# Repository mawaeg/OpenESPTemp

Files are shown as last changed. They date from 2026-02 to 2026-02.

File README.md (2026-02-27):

# OpenESPTemp

**OpenESPTemp** is an open-source, battery-powered temperature and environmental monitoring sensor built using an ESP32-C6 and a BME280 sensor. It is designed for integration into IoT systems.

The PCB is designed to operate with a rechargeable LiFePo4 AA battery. This repository includes the PCB design, a 3D-printable case, and basic firmware.

<div style="display: flex;">
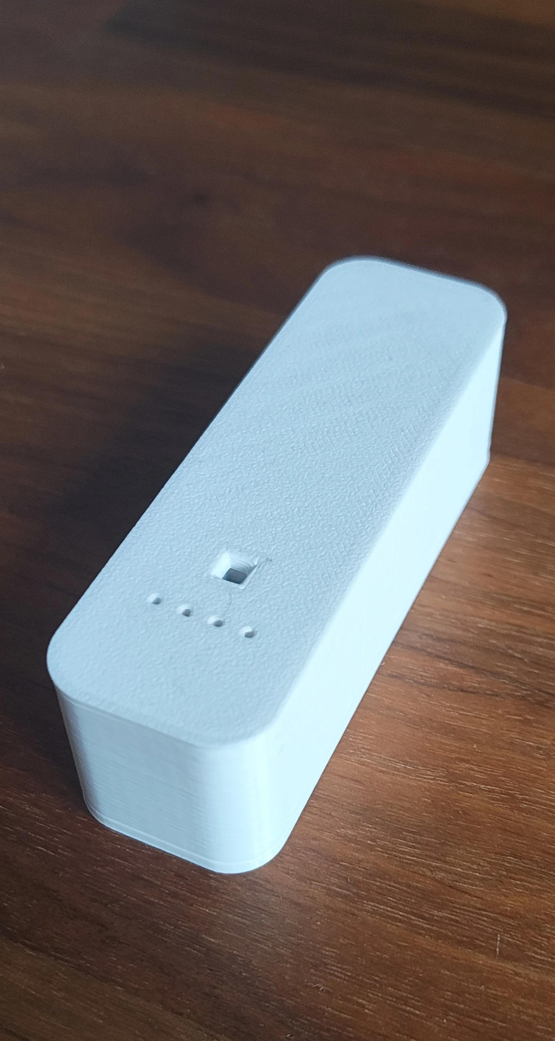
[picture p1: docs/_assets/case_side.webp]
Case Side
   
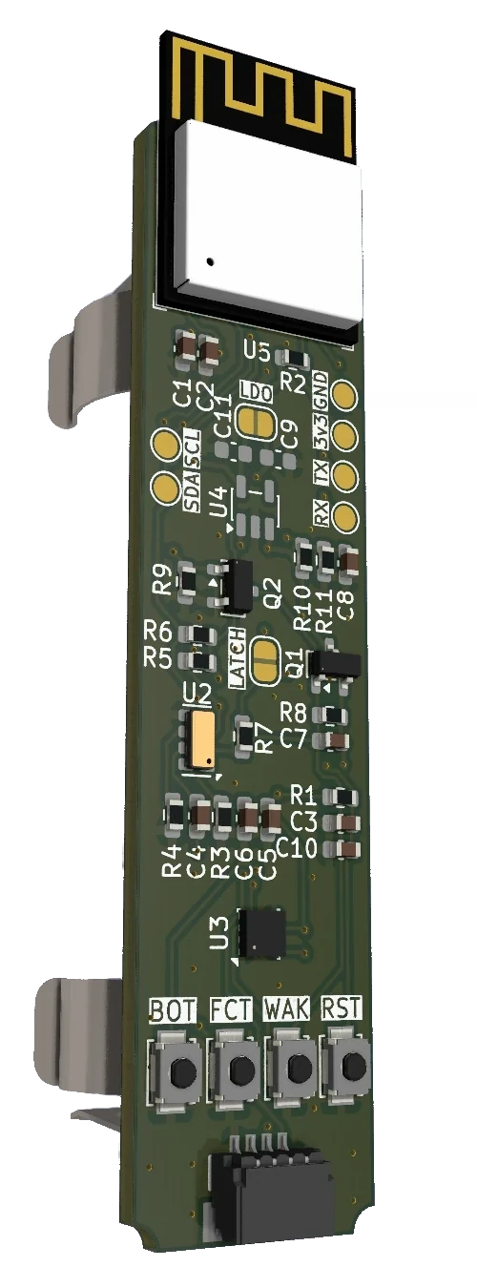
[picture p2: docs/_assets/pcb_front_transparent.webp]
PCB Front
   
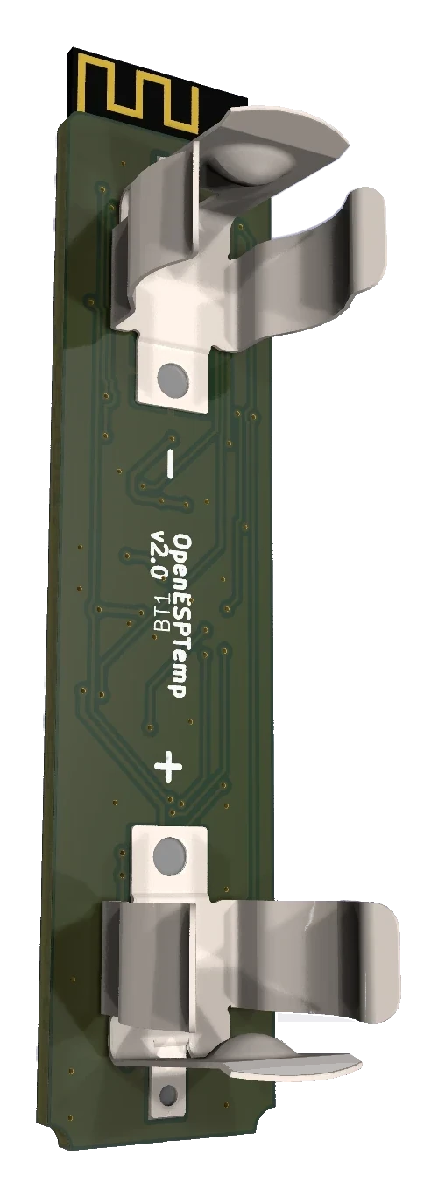
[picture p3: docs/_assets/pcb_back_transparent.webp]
PCB Back
   
</div>

---

## ✨ Features

- **Temperature Monitoring**: Provides readings using the BME280 sensor.
- **Environmental Sensing**: Includes humidity and pressure measurements.
- **Low Power**: Optimized for battery-powered operation (under 200nA power consumption while sleeping).
- **Battery Monitoring**: Allows monitoring of the battery voltage.
- **ESP32-C6 Microcontroller**: Handles wireless communication and processing.
- **Customizable PCB**: Features a Qwiic connector and the option to use an LDO when not using a LiFePo4 battery.
- **Open Source**: Fully customizable for specific use cases.
- **OTA updates**: Possibility to update the firmware over the air using ElegantOTA

---

## 🚀 Getting Started

### 1. The PCB

The PCB can be ordered from any PCB manufacturer (e.g., JLCPCB). It can be ordered as single boards or in panels of 5.

- **Manufacturing Files & BOM**: Included in the latest release. The Interactive HTML BOM (iBOM) is recommended for manual assembly.
- **SMT Assembly**: If using an SMT service, you will need to generate the BOM and position files yourself.

> **💡 Note:** You will need two Keystone 53 battery contacts; the BOM only mentions one.

### 2. Additional Parts

| Part | Quantity | Recommendation / Link | Note |
| :--- | :---: | :--- | :--- |
| **LiFePo4 AA (14500) battery (!Normal AA batteries won't work!)** | 1 | [LiFePo4 battery](https://de.aliexpress.com/item/1005005870958670.html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) | Any 3.2V LiFePo4 battery should work |
| **3D Printing Filament (PETG)** | ~50g | [White PETG Filament](https://www.nobufil.com/product-page/filament-petg-white) | |
| **UART to USB Adapter** | 1 | [CP2102 Adapter](https://de.aliexpress.com/item/1005006742102516.html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) | |
| **Pogo Pin Adapter** *(Optional)* | 1 | [4-Pin Prototyping Clamps](https://de.aliexpress.com/item/1005007887384238.html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) | Avoids soldering to test points. |

---

## 🛠️ Hardware Assembly

1. **Prepare the PCB**: Solder the components onto the PCB (if not using an SMT service).
   > **ℹ️ Info:** The LDO Solder Jumper is pre-closed for LiFePO4 battery use. If you choose to install an LDO, ensure you cut/open the jumper first.

   > **💡 Note:** If using a Pogo Adapter to flash the firmware, it should be flashed before mounting the battery holders, as the battery holder blocks access to the pins with the adapter.
2. **Print the Case**: Print using standard settings with a 0.2 mm layer height -  no supports needed.
   - The case does not require any screws, it holds together with snap connections
3. **Flash the Firmware**: Follow the instructions below to flash, and configure Wi-Fi/REST endpoint.
4. **Insert the Battery**:
   > **🛑 Warning:** Check the polarity carefully. Never connect the USB to UART adapter and the battery at the same time.
5. **Wake**: Press the WAK button for about a second. The sensor will start sending data periodically.

<div style="display: flex; gap: 20px;">
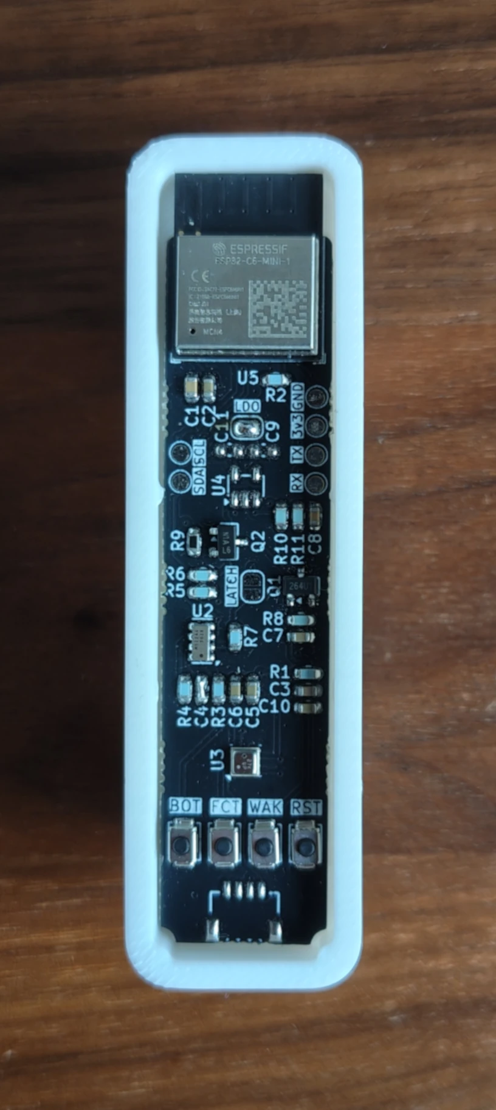
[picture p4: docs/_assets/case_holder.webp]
Case Pcb Holder
   
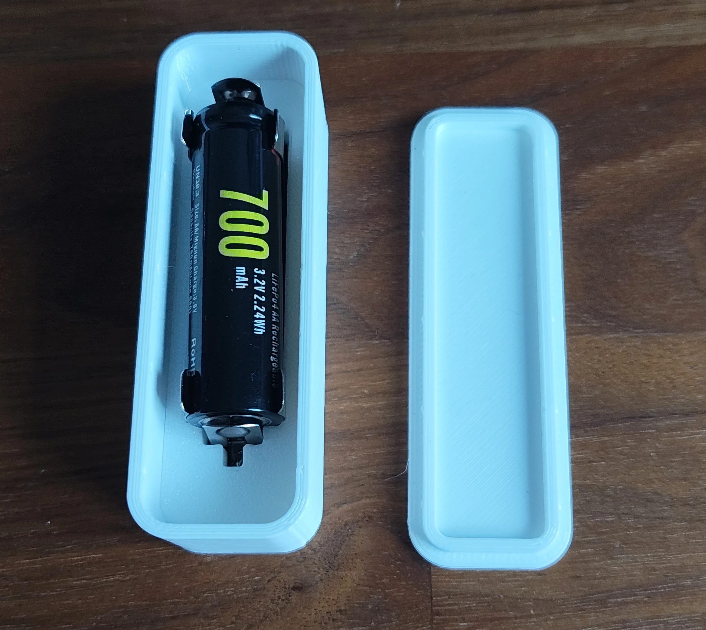
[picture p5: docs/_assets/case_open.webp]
Case open
   
</div>

---

## 💻 Firmware

By default, the sensor connects to a specified Wi-Fi network and sends data to a REST API endpoint every 15 minutes.

The firmware also allows to update itself using Over The Air updates using [ElegantOTA](https://github.com/ayushsharma82/ElegantOTA).
Read more about that [here](#flash-using-ota-update).

> **💡 Note:** Newer [releases](https://github.com/mawaeg/OpenESPTemp/releases) include a pre-compiled `.bin` file. If you use this, you can skip the compilation step.

### Compiling (PlatformIO)

The firmware can be compiled and flashed with [PlatformIO](https://platformio.org/). You can build in debug mode (to get Serial debug information) or release mode:

```bash
# Debug mode
platformio run --environment esp32-c6-debug

# Release mode
platformio run --environment esp32-c6
```

The firmware has to be flashed via the Serial Interface once. Afterwards it can be updated with [OTA updates](#flash-using-ota-update).

### Flashing

**Wiring:** Connect the UART to USB adapter to the PCB:

| UART Adapter | Direction | PCB | Note |
| :--- | :---: | :--- | :--- |
| **3V3** | ⟷ | **3V3** | Use 3.3V only (do not use 5V) |
| **GND** | ⟷ | **GND** | Common ground is required |
| **TX** | ⟶ | **RX** | Connect Transmit to Receive |
| **RX** | ⟵ | **TX** | Connect Receive to Transmit |

> **ℹ️ Info:** Remember to **cross** the data lines! The **TX** (Transmit) pin on the adapter must connect to the **RX** (Receive) pin on the PCB, and vice versa.

> **🛑 Warning:** You must disconnect the battery before connecting the UART to USB adapter!

#### Option A: Flashing via PlatformIO
Run the following command:
```bash
platformio run --target upload --environment esp32-c6
```
When `Looking for upload port...` appears in the console, put the ESP32 into boot mode:
1. Push the Reset and Boot buttons at the same time.
2. Release the Reset button while keeping the Boot button pressed.
3. The upload will start; release the Boot button.

#### Option B: Flashing via esptool (Precompiled Binary)
Flash the binary using [esptool](https://github.com/espressif/esptool):
```bash
python -m esptool --chip esp32-c6 --port <your-port> --baud 460800 write_flash -z 0x1000 firmware.bin
```
*(Put the ESP32 into boot mode as described above, and replace `<your-port>` with the correct serial port.)*

### Flash using OTA update

The firmware allows to update itself via OTA updates. For that to work the firmware has to be flashed via UART initially.

This is how to trigger a OTA update.
1. Follow steps 1 and 2 of [Reconfigure the device](#reconfigure-the-device)
4. Open **`http://192.168.4.1/update`** in a browser.
5. Here you can upload a new binary (Either get it from the [releases page](https://github.com/mawaeg/OpenESPTemp/releases) or compile it yourself as described [here](#compiling-(platformio))).
6. When uploading while powered by battery you should press and hold the WAK button during the update

---

## ⚙️ Configuration

After flashing, press the Reset button once to start the firmware. If unconfigured, the device will create a Wi-Fi network for setup:

1. Connect to the **`OpenESPTemp Configurator`** Wi-Fi network.
2. Open **`http://192.168.4.1`** in a browser.
3. Configure the following fields in the form:
   - **SSID**: Target Wi-Fi network name.
   - **Password**: Target Wi-Fi network password.
   - **Post URL**: The URL for the POST request.
   - **Authorization**: The Bearer token for authentication (do not include "Bearer", only the token).
4. Click submit. The configuration will be saved, and the device will restart.
5. The sensor will now operate as expected.

### Reconfigure the device

To reconfigure the OpenESPTemp after it has already been configured once, you need do the following:
1. Bring the OpenESPTemp in config mode:
   1. When connected to UART: Press and hold FCT button and press RST shortly. Release FCT after ~6 seconds
   2. When running with battery: Press and hold FCT button and press WAK for around a second. Release FCT after ~6 seconds
2. The OpenESPTemp will create a network called  **`OpenESPTemp Configurator`**. Connect to it.
3. Open **`http://192.168.4.1`** in a browser an reconfigure the fields. Refer to [⚙️ Configuration](#⚙️-configuration)

---

## ⚡ Power consumption

The OpenESPTemp aims to have a very low power consumption.

During sleep, the power consumption is below 200nA (200nA is the limit of the PPK 2, it is probably at around 50nA according to the RV3028-C7 datasheet):

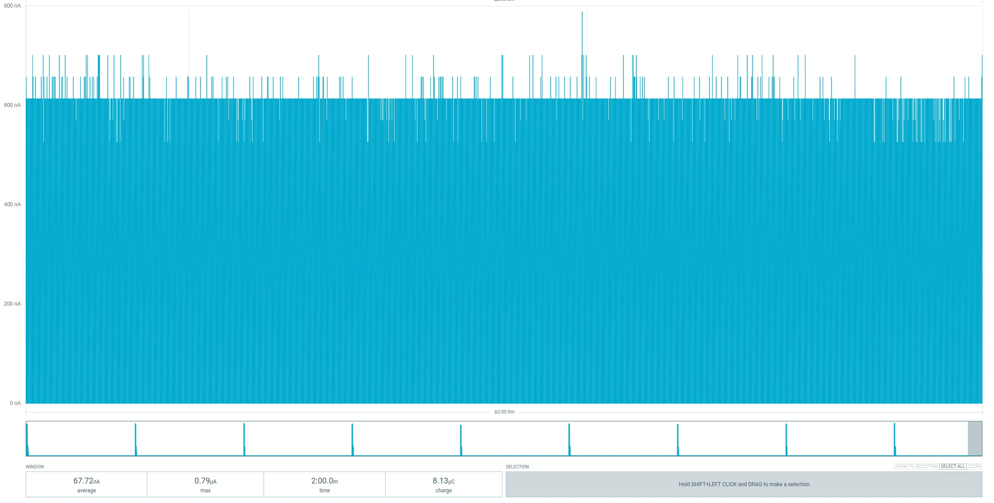
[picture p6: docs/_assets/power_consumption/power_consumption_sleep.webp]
Power consumption sleep


The power consumption for a whole cycle (15 min with sending data once) looks like this:

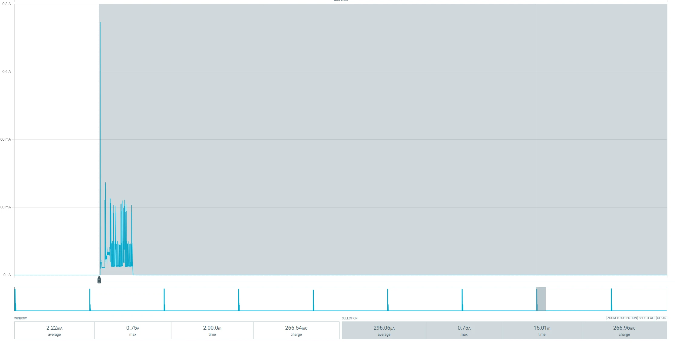
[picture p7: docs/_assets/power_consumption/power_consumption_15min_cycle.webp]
Power consumption 15 min cycle


The power consumption for active mode (sending data) looks the following:

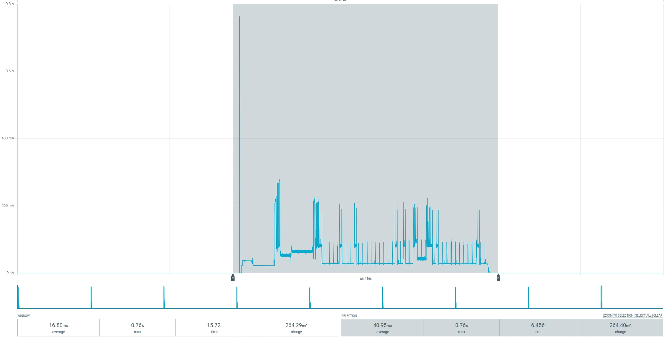
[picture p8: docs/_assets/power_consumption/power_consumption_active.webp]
Power consumption active


---

## 📐 PCB Design

The PCB was created using KiCad 9.0, the project files are located under [/electronics](/electronics).

The power latch used in this design was inspired by [this](https://circuitcellar.com/resources/quickbits/soft-latching-power-circuits/) article.

To generate a panel yourself using the provided script:
1. Install [KiKit](https://github.com/yaqwsx/KiKit).
2. Execute `/electronics/panelize.sh`.

The panel with the existing config looks like this:

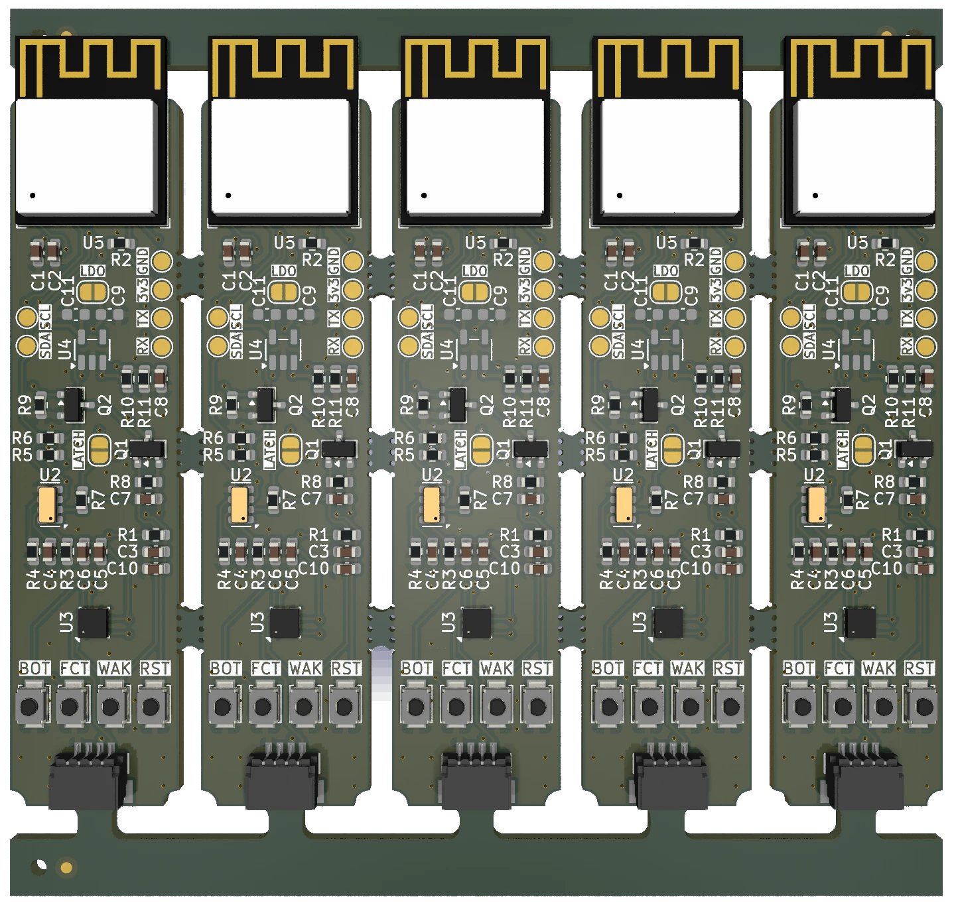
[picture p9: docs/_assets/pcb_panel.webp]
Flash wiring


---

## 🧊 CAD

The case was created using Onshape. To edit the case yourself click [here](https://cad.onshape.com/documents/398f777c8db5f4a69ffcddaa/w/b07485d077929fc2f0119cac/e/3395ca67b8682bc329248728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) and copy the project.

The current STL files are included in the repo under [/cad](/cad).

---

## 🚧 Troubleshooting

TBD

---

## 🗺️ Coming Next

- [ ] Include mounting bracket for the case
- [ ] Include HomeAssistant integration

---

## 📄 License

This project is licensed under the GNU General Public License v3.0. See the [LICENSE](LICENSE) file for details.

### Hardware Libraries
Various libraries were used to create the PCB. Copies of most libraries are included in `/electronics/libs/` to ensure the KiCad project works without manual installation.

Some of these libraries are licensed under their respective licenses. Please review the `README.md` file in the library folders.

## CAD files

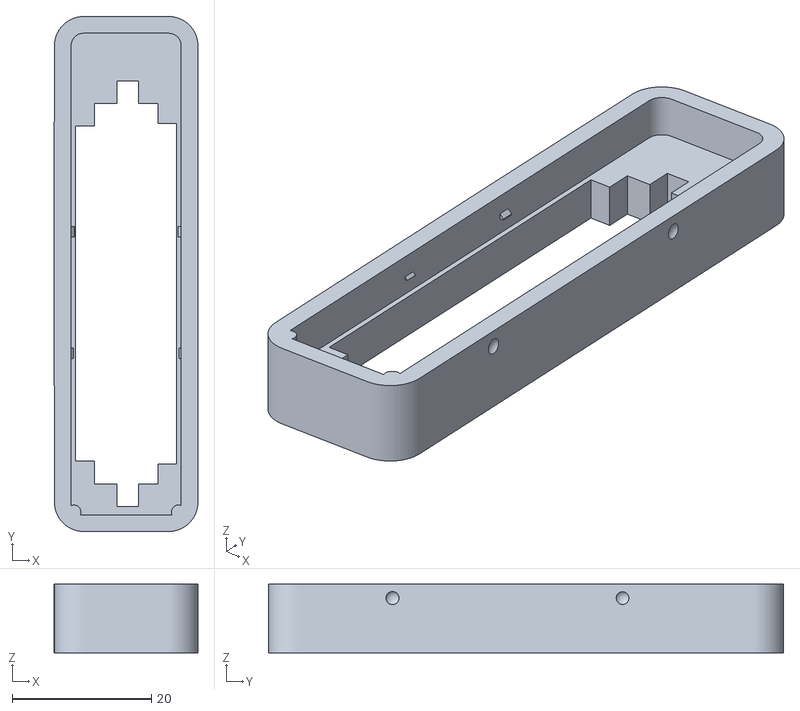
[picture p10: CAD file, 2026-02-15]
cad/pcb-holder.stl
20.7 x 73.9 x 9.86

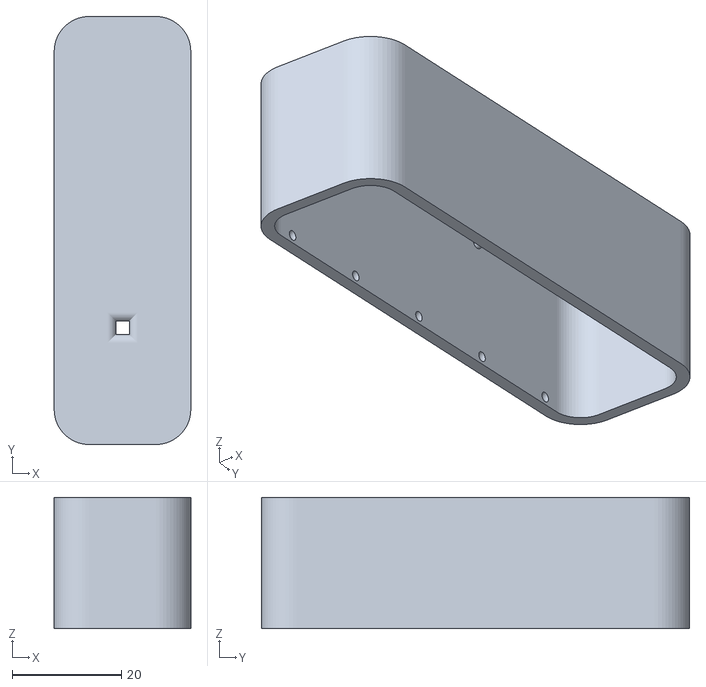
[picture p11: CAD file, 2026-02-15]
cad/case.stl
25.0 x 78.3 x 24.0

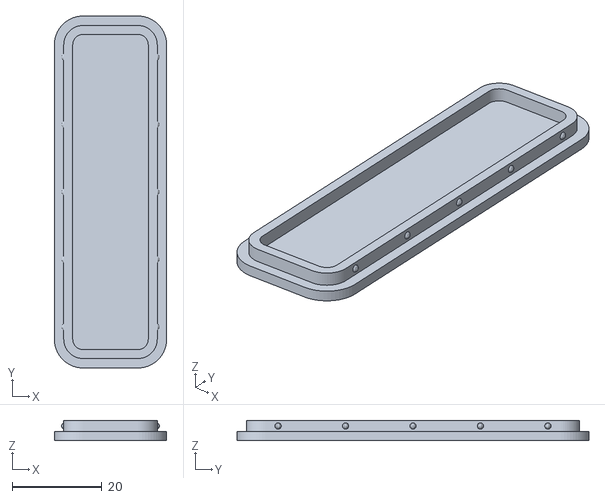
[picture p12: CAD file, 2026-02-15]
cad/top.stl
25.0 x 78.3 x 4.50

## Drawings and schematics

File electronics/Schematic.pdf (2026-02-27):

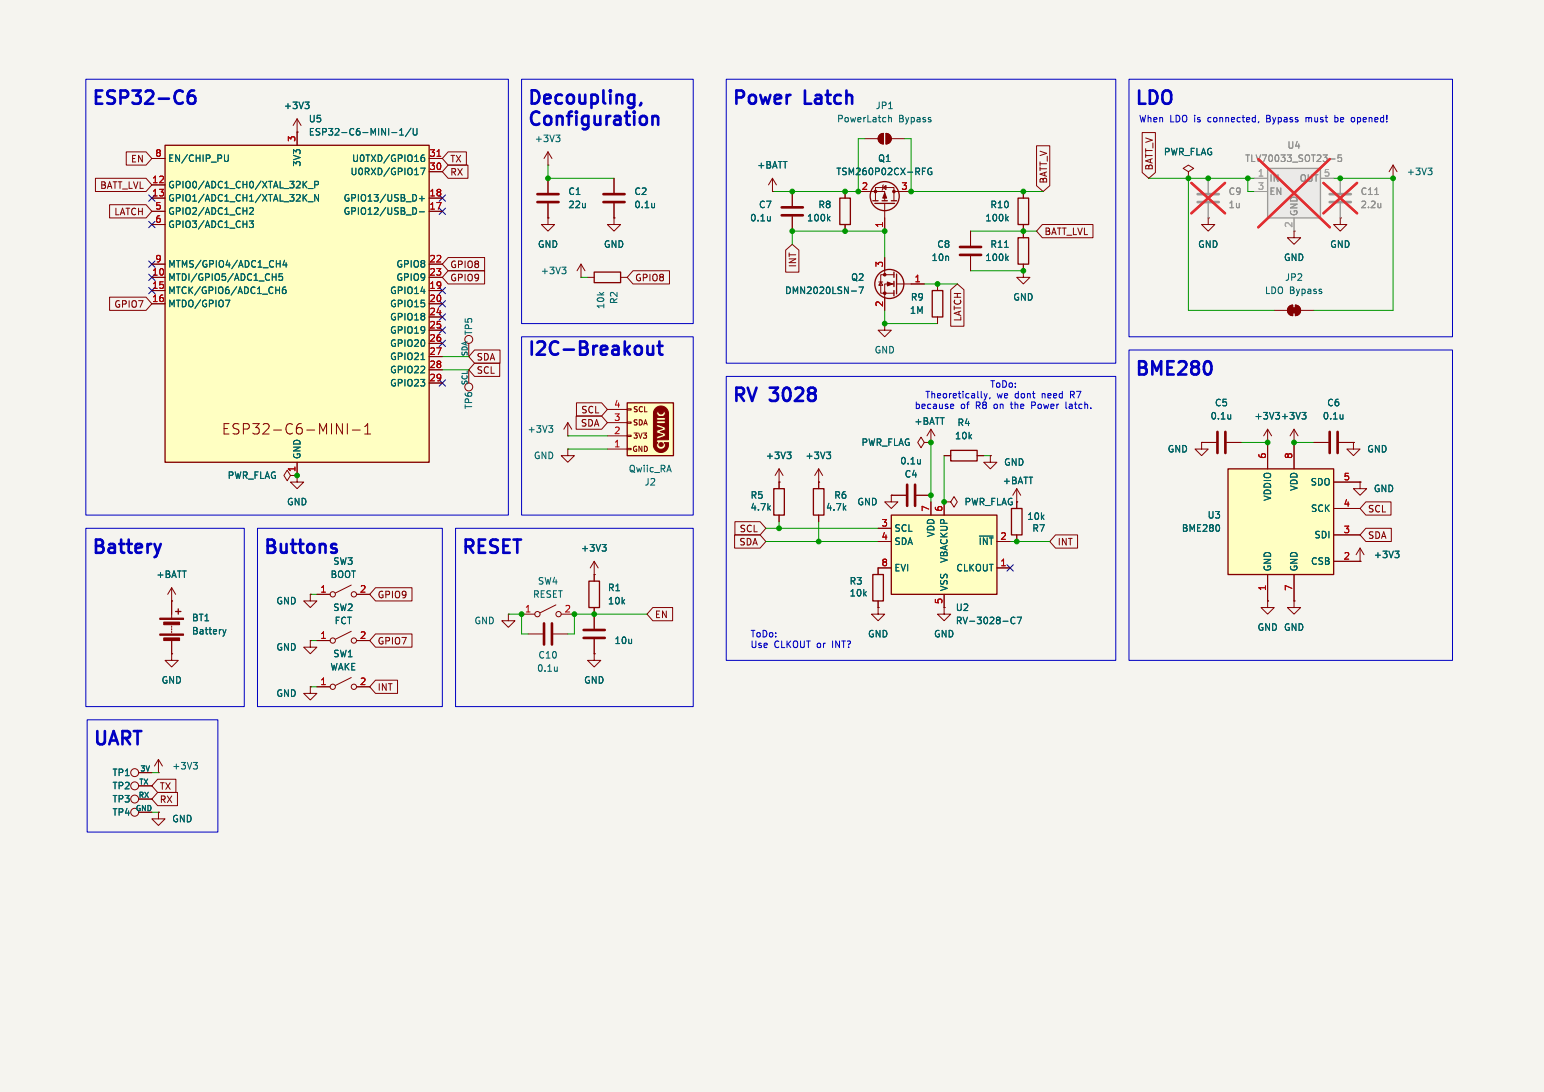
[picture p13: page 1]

7 SDO 5 SCK 4 SDI 3 CSB 2 GND Q1 TSM260P02CX-RFG

3 2 Q2 DMN2020LSN-7 TP4 GND TP3 RX GND GND GND

7 SDO 5 SCK 4 SDI 3 CSB 2 U3 BME280 TP6 SCL

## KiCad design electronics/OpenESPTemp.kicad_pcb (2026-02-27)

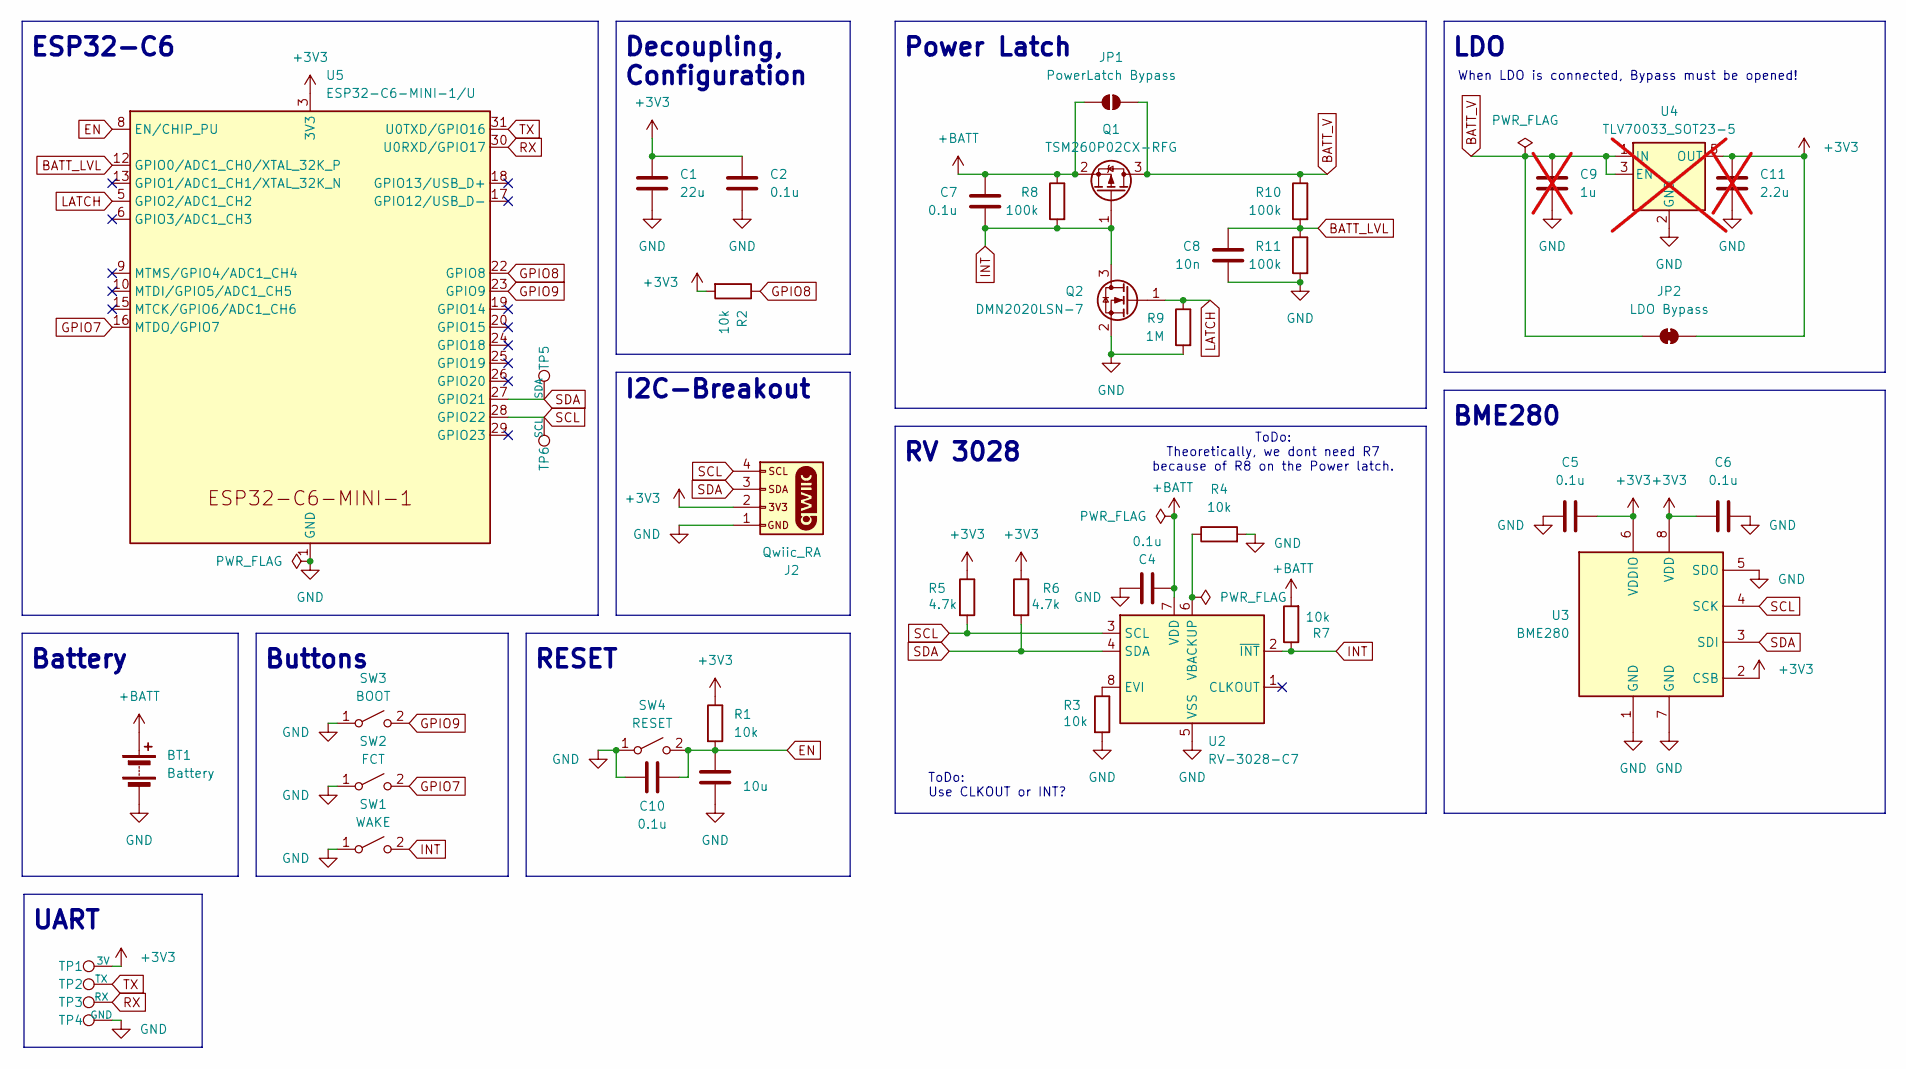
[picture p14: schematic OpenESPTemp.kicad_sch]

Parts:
BT1: Battery; Keystone_53_Dual
C1: 22u; C_0603_1608Metric
C2, C4, C5, C6, C7, C10: 0.1u; C_0603_1608Metric
C3: 10u; C_0603_1608Metric
C8: 10n; C_0603_1608Metric
C9: 1u; C_0603_1608Metric; not fitted
C11: 2.2u; C_0603_1608Metric; not fitted
J2: Qwiic_RA; JST_1x04_P1.0mm_Horizontal_SMD
JP1: PowerLatch Bypass; SolderJumper-2_P1.3mm_Open_RoundedPad1.0x1.5mm
JP2: LDO Bypass; SolderJumper-2_P1.3mm_Bridged_RoundedPad1.0x1.5mm
Q1: TSM260P02CX-RFG; SOT-23
Q2: DMN2020LSN-7; SOT-23
R1, R2, R3, R4, R7: 10k; R_0603_1608Metric
R5, R6: 4.7k; R_0603_1608Metric
R8, R10, R11: 100k; R_0603_1608Metric
R9: 1M; R_0603_1608Metric
SW1: WAKE; SW_SPST_B3U-1000P
SW2: FCT; SW_SPST_B3U-1000P
SW3: BOOT; SW_SPST_B3U-1000P
SW4: RESET; SW_SPST_B3U-1000P
TP1: 3V; TestPoint_Pad_D1.5mm
TP2: TX; TestPoint_Pad_D1.5mm
TP3: RX; TestPoint_Pad_D1.5mm
TP4: GND; TestPoint_Pad_D1.5mm
TP5: SDA; TestPoint_Pad_D1.5mm
TP6: SCL; TestPoint_Pad_D1.5mm
U2: RV-3028-C7; MicroCrystal_C7_SON-8_1.5x3.2mm_P0.9mm
U3: BME280; Bosch_LGA-8_2.5x2.5mm_P0.65mm_ClockwisePinNumbering
U4: TLV70033_SOT23-5; SOT-23-5; not fitted
U5: ESP32-C6-MINI-1/U; ESP32-C6-MINI-1

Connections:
+3V3: C1.1, C2.1, C5.2, C6.1, C11.1, J2.2, JP2.2 (B), R1.1, R2.2, R5.1, R6.1, TP1.1, U3.2 (CSB), U3.6 (VDDIO), U3.8 (VDD), U4.5 (OUT), U5.3 (3V3)
+BATT: BT1.1 (+), C4.1, C7.1, JP1.1 (A), Q1.2 (S), R7.2, R8.1, U2.7 (VDD)
BATT_LVL: C8.1, R10.2, R11.1, U5.12 (GPIO0/ADC1_CH0/XTAL_32K_P)
BATT_V: C9.1, JP1.2 (B), JP2.1 (A), Q1.3 (D), R10.1, U4.1 (IN), U4.3 (EN)
EN: C3.1, C10.1, R1.2, SW4.2 (B), U5.8 (EN/CHIP_PU)
GND: BT1.2 (-), C1.2, C2.2, C3.2, C4.2, C5.1, C6.2, C8.2, C9.2, C10.2, C11.2, J2.1, Q2.2 (S), R3.2, R4.2, R9.2, R11.2, SW1.1 (A), SW2.1 (A), SW3.1 (A), SW4.1 (A), TP4.1, U2.5 (VSS), U3.1 (GND), U3.5 (SDO), U3.7 (GND), U4.2 (GND), U5.1 (GND), U5.2 (GND), U5.11 (GND), U5.14 (GND), U5.36 (GND), U5.37 (GND), U5.38 (GND), U5.39 (GND), U5.40 (GND), U5.41 (GND), U5.42 (GND), U5.43 (GND), U5.44 (GND), U5.45 (GND), U5.46 (GND), U5.47 (GND), U5.48 (GND), U5.49 (GND), U5.50 (GND), U5.51 (GND), U5.52 (GND), U5.53 (GND)
GPIO7: SW2.2 (B), U5.16 (MTDO/GPIO7)
GPIO8: R2.1, U5.22 (GPIO8)
GPIO9: SW3.2 (B), U5.23 (GPIO9)
INT: C7.2, Q1.1 (G), Q2.3 (D), R7.1, R8.2, SW1.2 (B), U2.2 (~INT)
LATCH: Q2.1 (G), R9.1, U5.5 (GPIO2/ADC1_CH2)
unnamed: R3.1, U2.8 (EVI)
unnamed: R4.1, U2.6 (VBACKUP)
RX: TP3.1, U5.30 (U0RXD/GPIO17)
SCL: J2.4, R5.2, TP6.1, U2.3 (SCL), U3.4 (SCK), U5.28 (GPIO22)
SDA: J2.3, R6.2, TP5.1, U2.4 (SDA), U3.3 (SDI), U5.27 (GPIO21)
TX: TP2.1, U5.31 (U0TXD/GPIO16)

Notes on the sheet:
Power Latch
I2C-Breakout
Decoupling, Configuration
ToDo: Theoretically, we dont need R7 because of R8 on the Power latch.
RV 3028
When LDO is connected, Bypass must be opened!
ESP32-C6
LDO
Buttons
BME280
RESET
Battery
ToDo: Use CLKOUT or INT?
UART

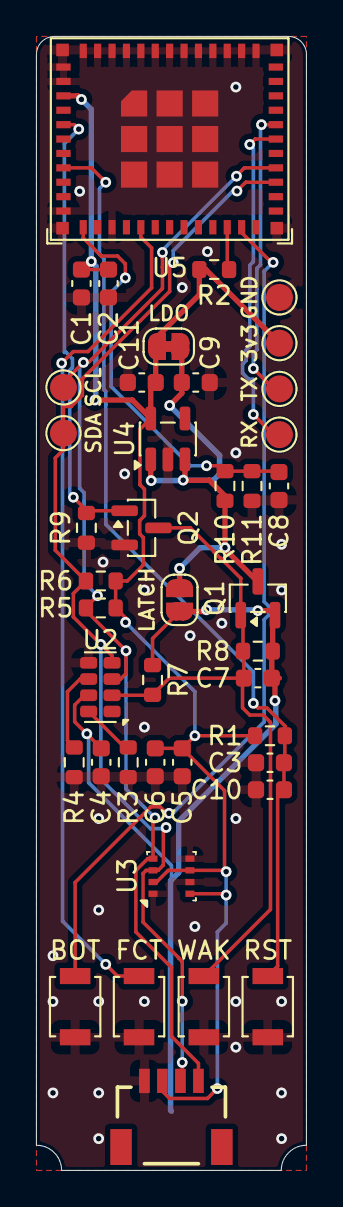
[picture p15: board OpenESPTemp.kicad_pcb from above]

Board: 2 copper layers, 15.0 x 63.0 mm, 42 parts (1 on the bottom side), 17 nets.

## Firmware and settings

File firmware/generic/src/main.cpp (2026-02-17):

#include <Arduino.h>
#include <WiFi.h>
#include <HTTPClient.h>
#include <NTPClient.h>
#include <WiFiUdp.h>

#include <Wire.h>
#include <Adafruit_Sensor.h>
#include <Adafruit_BME280.h>
#include <Melopero_RV3028.h>

#include "CredentialManager.h"
#include "ConfigurationWebServer.h"

// The sleeptime in minutes
#define SLEEPTIME 15
// Time needed for reset with FCT pin
#define FCT_PIN_RESET_HOLD_TIME 5000

#define SDA_PIN 21
#define SCL_PIN 22
#define LATCH_PIN 2
#define VOLTAGE_PIN 0
#define FCT_PIN 7

Adafruit_BME280 bme;
WiFiUDP ntpUDP;
NTPClient timeClient(ntpUDP);
Melopero_RV3028 rtc;

CredentialManager manager;
ConfigurationWebServer configServer(manager);

float temperature = -1;
float humidity = -1;
float pressure = -1;
float voltage = -1;

bool fct_pin_reset_logic();
void initialize_wifi();
void initialize_timer();
bool initialize_bme();
void read_data();
void post_data();

void setup() {
  // Hold up the Power Latch
  pinMode(LATCH_PIN, OUTPUT);
  digitalWrite(LATCH_PIN, HIGH);

  pinMode(VOLTAGE_PIN, INPUT);


  delay(500);
  Wire.begin(SDA_PIN, SCL_PIN);

  #ifdef DEBUG
    Serial.begin(115200);
    Serial.println("Hello world!");
  #endif

  initialize_timer();

  if (fct_pin_reset_logic() || !manager.is_valid()){
    configServer.run(); //Only exists if configuration was successful.

    // Set CLKOUT = LOW -> Not used, reduces power consumption of RTC
    rtc.writeEEPROMRegister(0x35, 0b111);
  }

  // In case no connection is established esp sleeps 15 minutes.
  initialize_wifi();

  bool init_successful = initialize_bme();
  #ifdef DEBUG
    Serial.println("----");
  #endif

  // If sensor was initialized successful we want to read an post data.
  if (init_successful){
    read_data();
    post_data();
  }

  digitalWrite(LATCH_PIN, LOW);
}

void loop() {
  // This will never be called and therefore stay empty as the esp goes back to sleep after sending data in setup.
  digitalWrite(LATCH_PIN, LOW);
  delay(1000);
}

bool fct_pin_reset_logic(){
  pinMode(FCT_PIN, INPUT_PULLUP);

  if (digitalRead(FCT_PIN) != LOW){
    return false;
  }

  #ifdef DEBUG
    Serial.println("Starting FCT button reset hold time counter");
  #endif

  unsigned long start_time = millis();
  bool reset_done = false;

  while(digitalRead(FCT_PIN) == LOW){
    if (millis() - start_time > FCT_PIN_RESET_HOLD_TIME){
      reset_done = true;
      break;
    }
    delay(10);
  }
  #ifdef DEBUG
    if (reset_done){
        Serial.println("Reset was performed. Credentials have been deleted.");
    }
    else{
      Serial.println("Reset aborted. Credentials have NOT been deleted.");
    }
  #endif

  return reset_done;
}

void initialize_wifi(){
  #ifdef DEBUG
    Serial.println("Connecting to network.");
  #endif
  WiFi.setHostname("ESP32-C6-Temp");
  WiFi.begin(manager.get(SSID), manager.get(PASSWORD));

  uint8_t connect_counter = 0;
  while (WiFi.status() != WL_CONNECTED) {
    connect_counter++;
    if(connect_counter >= 10){
      // Sleep after 10 seconds
      #ifdef DEBUG
        Serial.println("Unable to connect to Wifi. Sleeping.");
      #endif
      digitalWrite(LATCH_PIN, LOW);
    }
    delay(1000);
    #ifdef DEBUG
      Serial.println("Connecting...");
    #endif
  }
  #ifdef DEBUG
    Serial.print("Connected with ip: ");
    Serial.println(WiFi.localIP());
  #endif
}

void initialize_timer(){
  rtc.initI2C();
  rtc.set24HourMode();
  rtc.setTime(2025, 12, 3, 5, 0, 0, 0);
  rtc.setDateModeForAlarm(false);
  rtc.enableAlarm(0, rtc.getHour(), rtc.getMinute() + SLEEPTIME, false, true, true, true);
  rtc.clearInterruptFlags();

  #ifdef DEBUG
    Serial.println("Clock and Alarm successfully set.");
  #endif
}

bool initialize_bme(){
  #ifdef DEBUG
    Serial.println("Initializing BME280");
  #endif
  int status = bme.begin(0x76, &Wire);
  bme.setSampling(Adafruit_BME280::MODE_FORCED,
                  Adafruit_BME280::SAMPLING_X1,
                  Adafruit_BME280::SAMPLING_X1,
                  Adafruit_BME280::SAMPLING_X1,
                  Adafruit_BME280::FILTER_OFF);

  if (!status){
    #ifdef DEBUG
      Serial.println("Could not find BME280.");
    #endif
    return false;
  }
  #ifdef DEBUG
    Serial.println("BME280 was successfully initialized!");
  #endif
  return true;
}

void read_data(){
  // Saving data
  temperature = bme.readTemperature();
  humidity = bme.readHumidity();
  pressure = bme.readPressure() / 100.0F;
  voltage = (analogReadMilliVolts(VOLTAGE_PIN) / 1000.0F)*2.0F;
  #ifdef DEBUG
    Serial.print("Temperature: ");
    Serial.println(temperature);
    Serial.print("Humidity: ");
    Serial.println(humidity);
    Serial.print("Pressure: ");
    Serial.println(pressure);
  #endif

  Wire.end();
}

void post_data(){
  #ifdef DEBUG
    Serial.println("Sending request");
  #endif
  HTTPClient httpClient;

  httpClient.setConnectTimeout(5000);
  //We do not need to set timeout as it is set to 5000 by default.

  #ifdef DEBUG
    Serial.println("Preparing data");
  #endif

  httpClient.begin(manager.get(POST_URL));
  httpClient.addHeader("Authorization", "Bearer " + manager.get(AUTHORIZATION));
  httpClient.addHeader("Content-Type", "application/json");

  String json_data = "{\"temperature\": \"" + String(temperature) + "\", \"humidity\": \"" + String(humidity) + "\", \"pressure\": \"" + String(pressure) + "\", \"voltage\": \"" + String(voltage) + "\"}";


  #ifdef DEBUG
    Serial.print("Sending request: ");
  #endif
  int request = httpClient.POST(json_data);
  #ifdef DEBUG
    Serial.println(request);
  #endif
  httpClient.end();

  #ifdef DEBUG
    Serial.println("Request was sent");
  #endif
}

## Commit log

2024-12-25 Update Readme for newest pcb version
2024-12-27 Update copy of pcb Also updated images and readme accordingly
2025-12-27 Initial Kicad PCB version
    This moves the PCB to a Kicad project.
    It also introduces a Power Latch triggered by an UltraLowPowerTimer to
    reduce power consumption
    [OpenESPTemp.kicad_pcb, OpenESPTemp.kicad_sch, power_latch.kicad_sch]
2025-12-27 Update firmware for new pcb
    - Migrate to esp32-c6 (uses pioarduino instead of platformio to have
    arduino support for esp32-c6)
    - Updates the pins used
    - integrates support for the Power Latch mechanism
2025-12-27 Update firmware dependencies
    Updates AsyncWebServer dependency and fixes error when compiling (with pioarduino)
    [main.cpp]
2026-02-03 Adding reset option with FCT button
    - When the button is pressed and hold for 5 seconds after the reset the stored credentials will be deleted
    - Button must already be pressed while resetting.
    [main.cpp]
2026-02-13 Minor improvements
    [OpenESPTemp.kicad_pcb]
2026-02-15 Update case stl files
    [case.stl, pcb-holder.stl, seal.stl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]
2026-02-15 Improve UART to USB wiring description
2026-02-16 Fix Pcb issues
    - Fix wrong connection of C4
    - Move symbol lib into libs/; Delete unused .kicad_sch file
    - Make LDO Solder Jumper Bridged by default
    - Fix temp notes file (Licenses.txt)
    [OpenESPTemp.kicad_pcb, OpenESPTemp.kicad_sch, power_latch.kicad_sch]
2026-02-17 Improve firmware
    - Configuring timer was done after wifi connection -> If no Wifi connection was established, ESP would sleep forever, this is now fixed
    - After the configServer ran, the CLKOUT of the RV3028 is now disabled to reduce power consumption
    - Remove stop_wifi(), as it just takes time and esp powers done completely nevertheless
    [main.cpp]
2026-02-17 Add power consumption section to README
2026-02-27 fix(electronics): Improve Schematic
    Improve schematic overall
    Add exported .pdf of current schematics
    [OpenESPTemp.kicad_pcb, OpenESPTemp.kicad_sch]
